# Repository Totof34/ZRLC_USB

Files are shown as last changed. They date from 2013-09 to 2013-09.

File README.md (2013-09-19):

ZRLC_USB
================

A small project to measure resistance, impedance, capacitance, inductance, input impedance of
amplifier, transformers, etc 

If you would have more information about this project please visit 
www.audiyofan.org

A link to the dedicated post 

http://www.audiyofan.org/forum/viewtopic.php?f=57&t=8121&start=30

It's just a box connected via USB , you don't need an external sound card to measure ZRLC,

You can use VisualAnalyser or an other program, A link to the dedicated to the software

http://www.sillanumsoft.org/ZRLC.htm

Under Linux no drivers is required
Under Windows you can find in the folder "Drivers_windows" all you need to run this box properly

PCB & schema are designed with Kicad

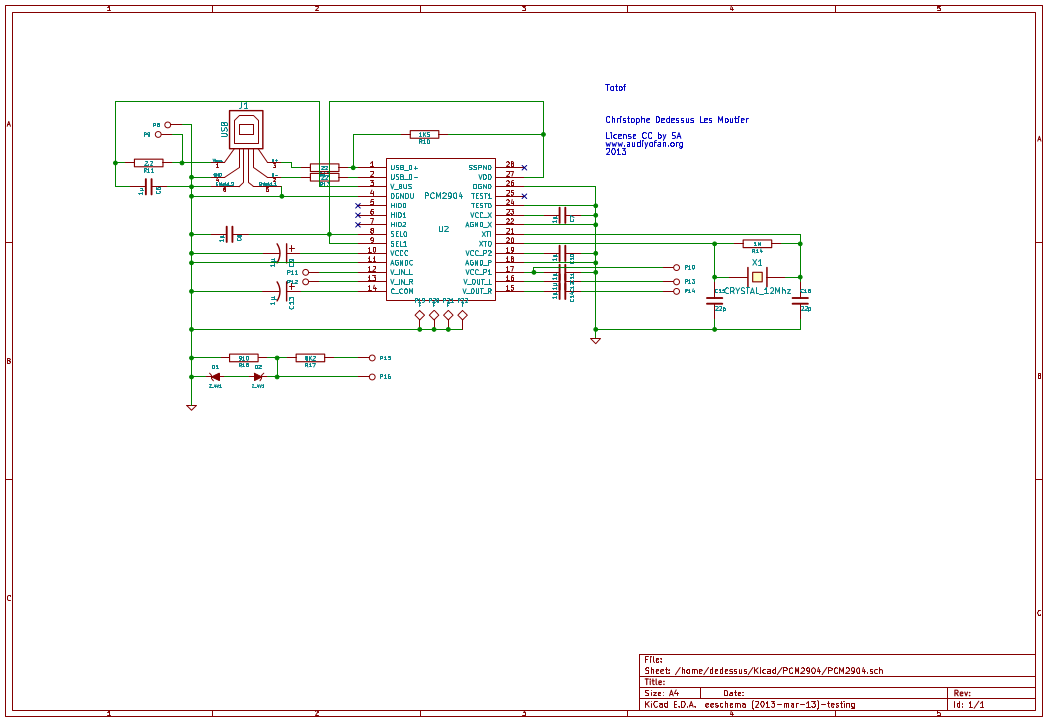
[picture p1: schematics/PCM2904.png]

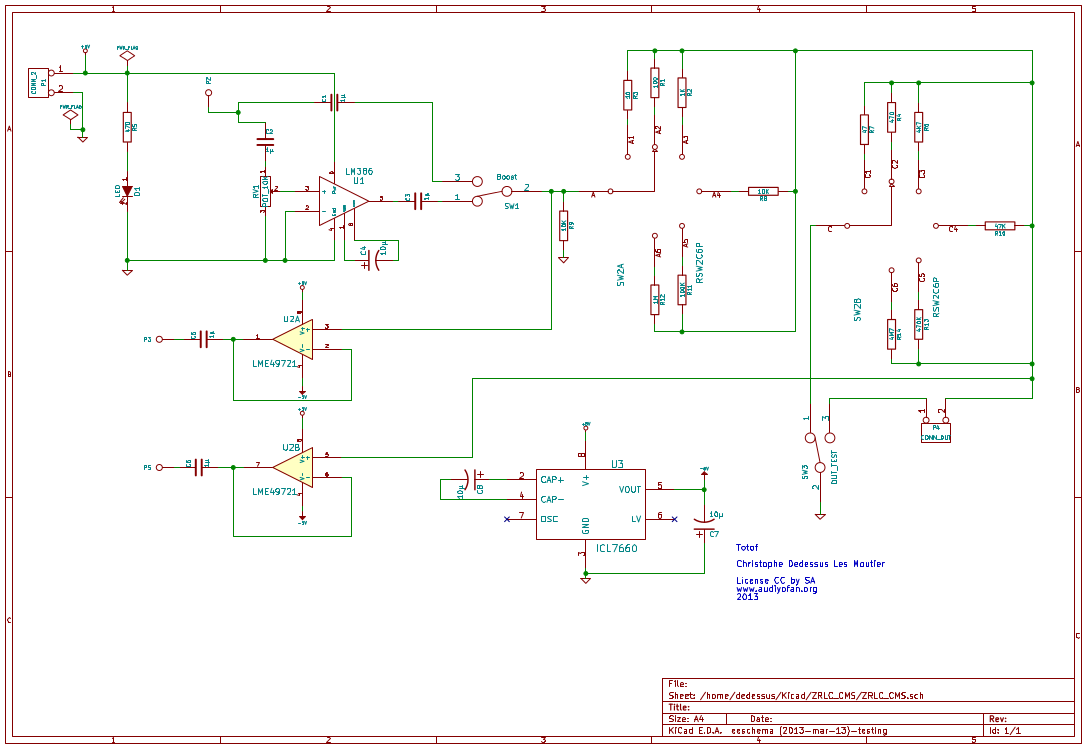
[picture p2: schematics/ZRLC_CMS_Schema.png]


All comments are welcome

Totof

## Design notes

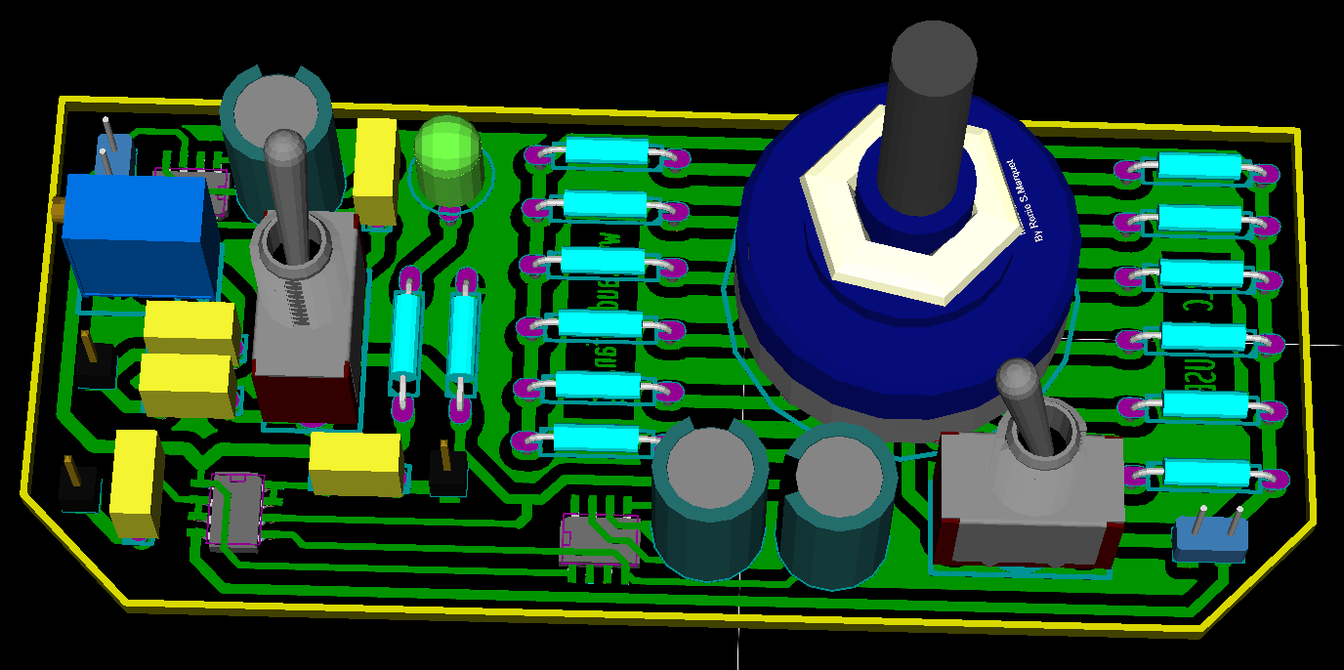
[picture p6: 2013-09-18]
images/ZRLC_CMS_3D.png

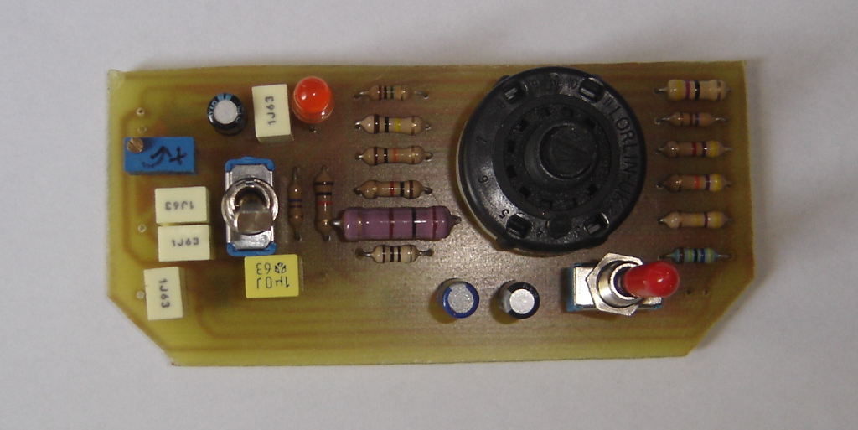
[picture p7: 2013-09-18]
images/PCB_ZRLC_CMS5.JPG

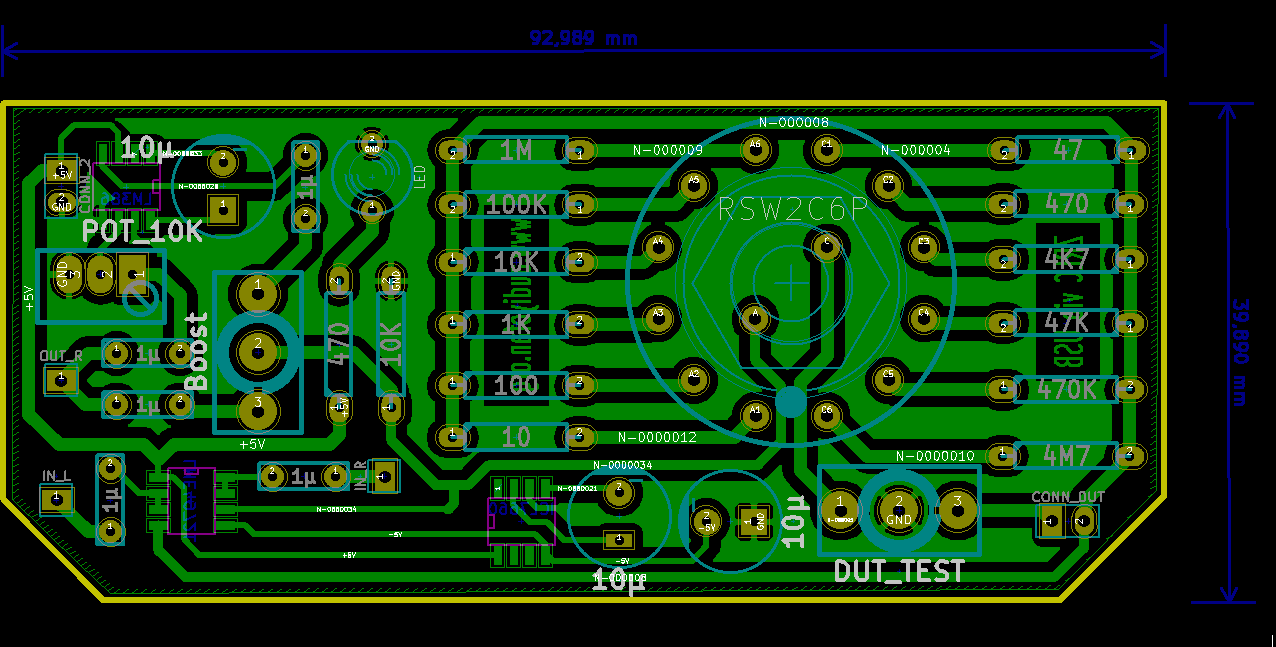
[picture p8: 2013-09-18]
images/ZRLC_CMS_PCB.png

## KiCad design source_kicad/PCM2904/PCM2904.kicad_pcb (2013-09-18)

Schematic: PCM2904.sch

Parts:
C6, C7, C8, C9, C10, C11, C12, C13, C14: 1µ
C15, C16: 22p
D1, D2: Z_4V1
J1: USB
P8: CONN_GND
P9: CONN_V+
P10: V_OUT
P11: V_IN_L
P12: V_IN_R
P13: V_OUT_L
P14: V_OUT_R
P15: CH2_IN
P16: CH2_OUT
P19, P20, P21, P22: F
R10: 1K5
R11: 2.2
R12, R13: 22
R14: 1M
R16: 910
R17: 8K2
U2: PCM2904
X1: CRYSTAL_12Mhz

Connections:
GND: C6.1, C7.1, C8.2, C9.2, C10.1, C11.1, C13.2, C15.2, C16.2, D1.2, J1.4 (GND), J1.5 (Shield_1), J1.6 (Shield_2), P8.1, P19.1, P20.1, P21.1, P22.1, R16.2, U2.4 (DGNDU), U2.11 (AGNDC), U2.18 (AGND_P), U2.22 (AGND_X), U2.24 (TEST0), U2.26 (DGND)
unnamed: C15.1, R14.2, U2.20 (XTO), X1.1
unnamed: C16.1, R14.1, U2.21 (XTI), X1.2
unnamed: C11.2, P10.1, U2.17 (VCC_P1)
unnamed: P11.1, U2.12 (V_IN_L)
unnamed: P12.1, U2.13 (V_IN_R)
unnamed: C12.1, P13.1
unnamed: C12.2, U2.16 (V_OUT_L)
unnamed: C14.1, P14.1
unnamed: C14.2, U2.15 (V_OUT_R)
unnamed: C10.2, U2.19 (VCC_P2)
unnamed: C7.2, U2.23 (VCC_X)
unnamed: P15.1, R17.1
unnamed: D2.2, P16.1, R16.1, R17.2
unnamed: D1.1, D2.1
unnamed: J1.3 (D+), R12.2
unnamed: R13.1, U2.2 (USB_D-)
unnamed: C6.2, R11.2, U2.3 (V_BUS)
unnamed: C8.1, R10.1, U2.8 (SEL0), U2.9 (SEL1), U2.27 (VDD)
unnamed: J1.2 (D-), R13.2
unnamed: C13.1, U2.14 (C_COM)
unnamed: C9.1, U2.10 (VCCC)
unnamed: J1.1 (Vbus), P9.1, R11.1
unnamed: R10.2, R12.1, U2.1 (USB_D+)

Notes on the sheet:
Totof Christophe Dedessus Les Moutier License CC by SA www.audiyofan.org 2013

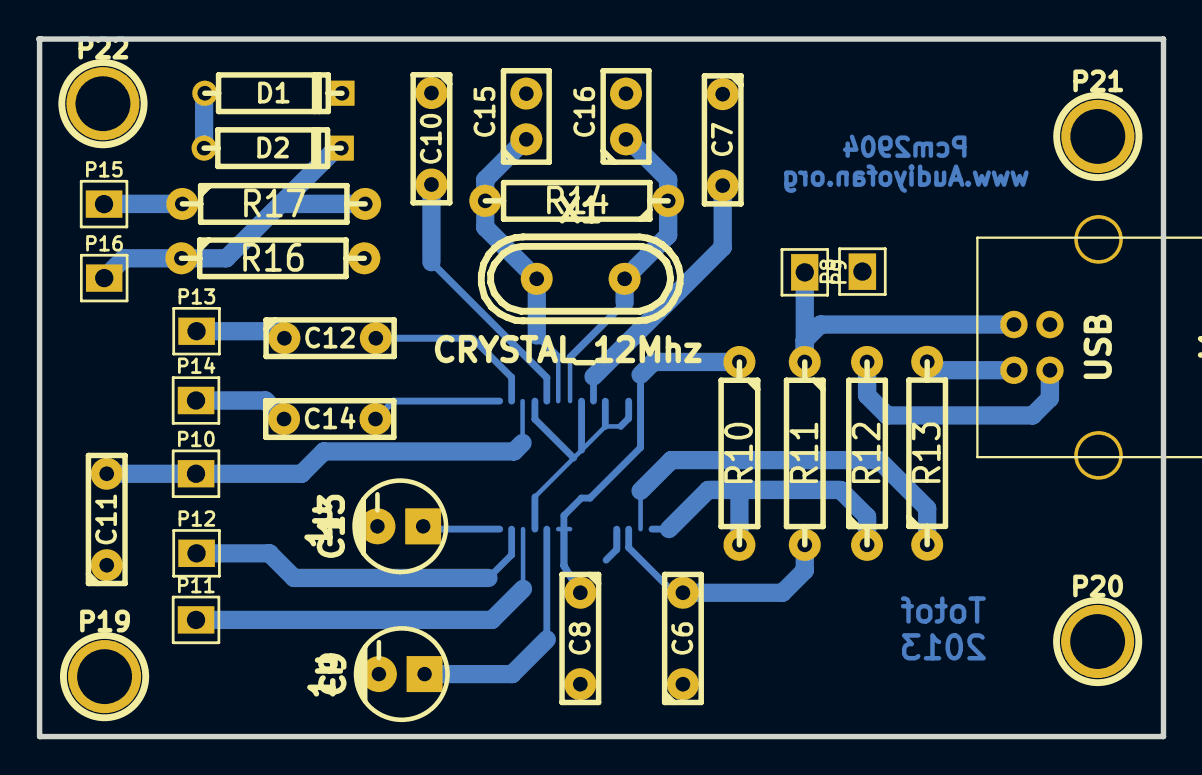
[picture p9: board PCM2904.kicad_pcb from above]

Board: 2 copper layers, 62.5 x 38.8 mm, 36 parts (1 on the bottom side), 24 nets.

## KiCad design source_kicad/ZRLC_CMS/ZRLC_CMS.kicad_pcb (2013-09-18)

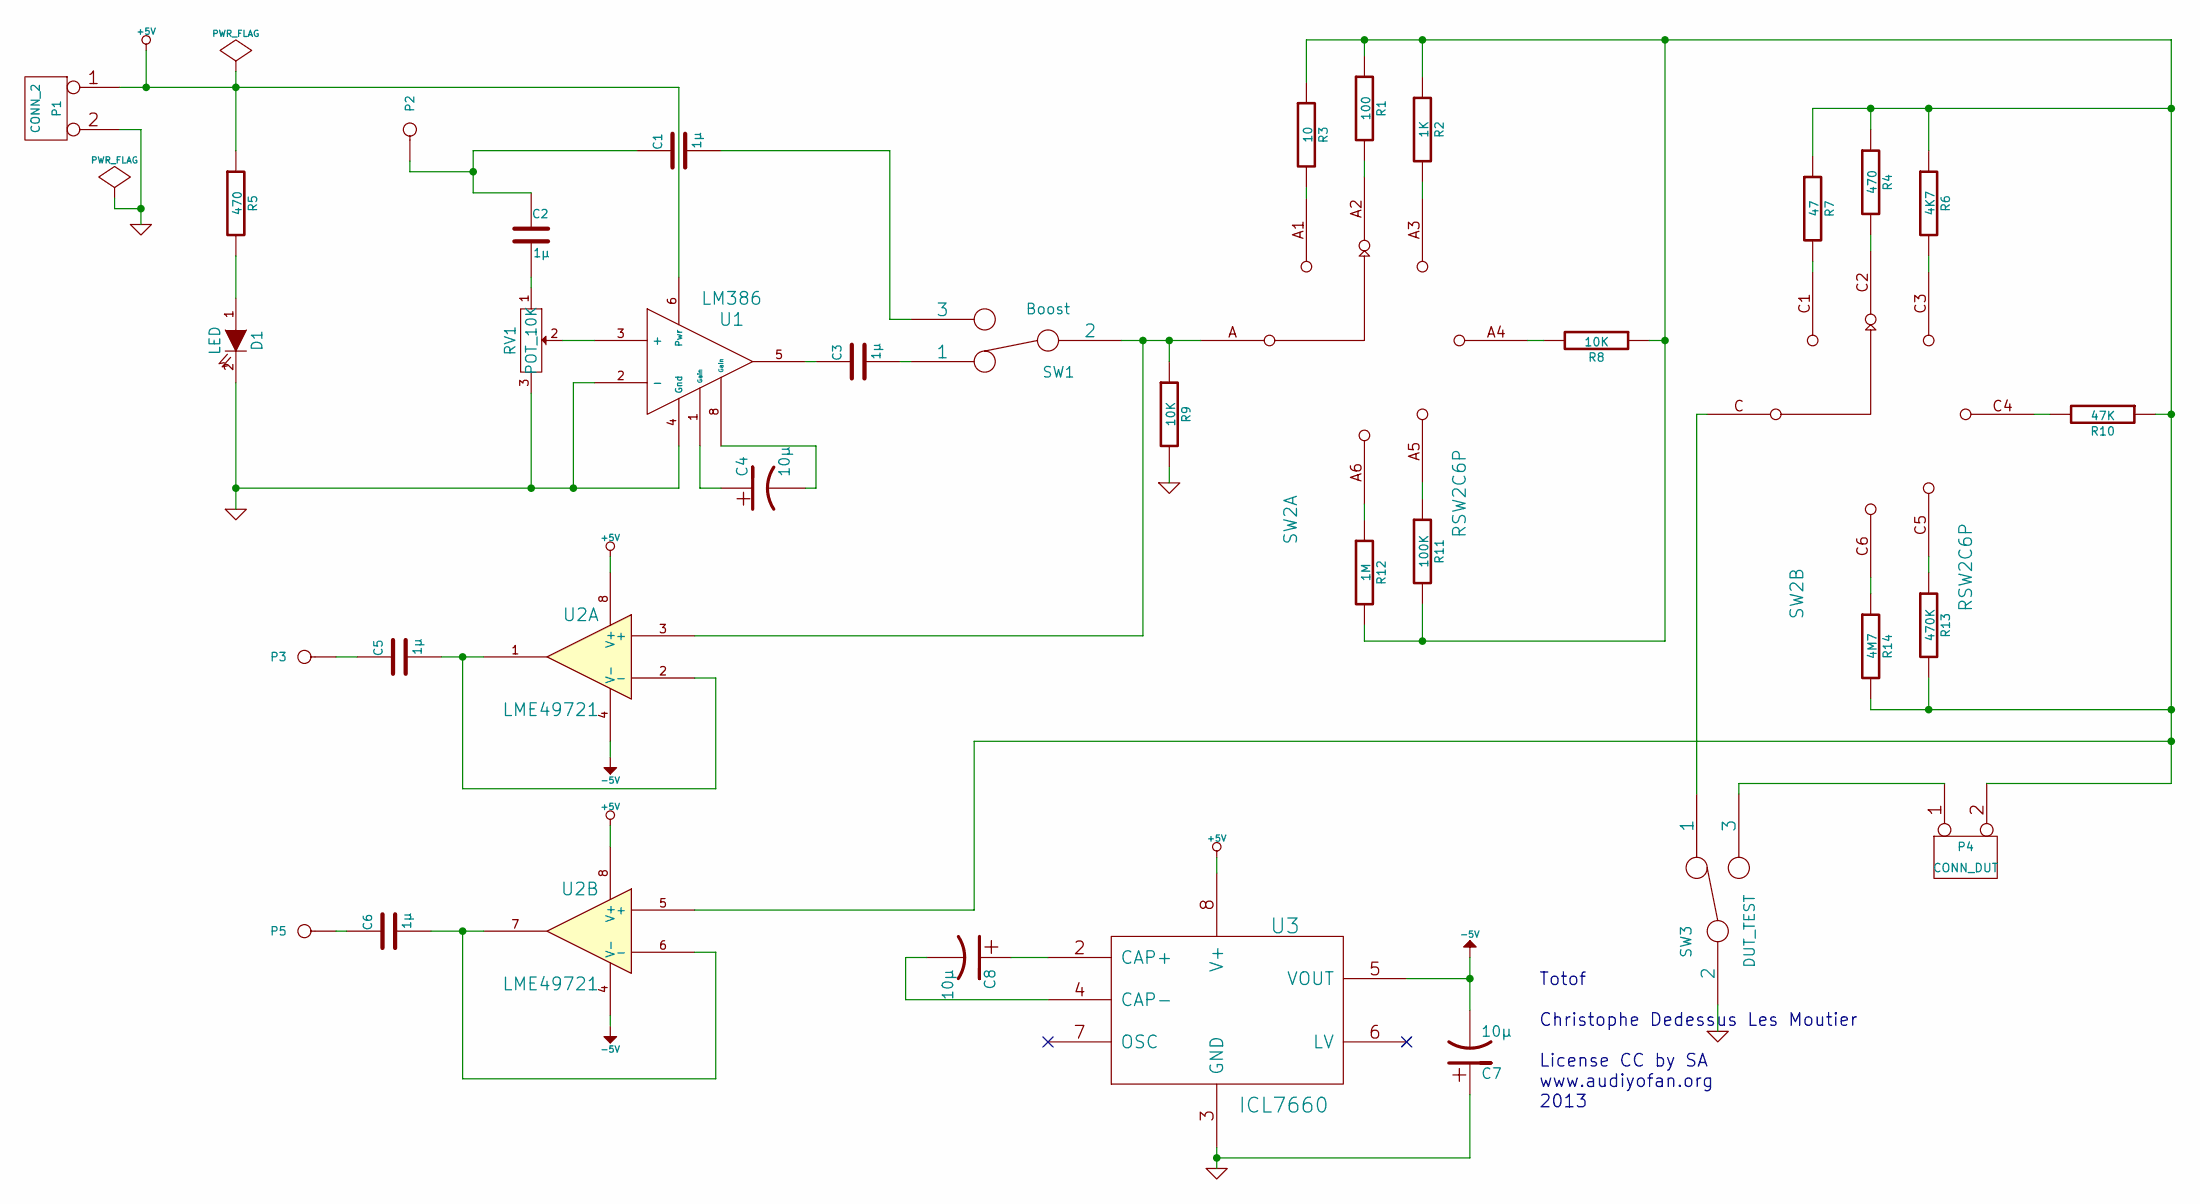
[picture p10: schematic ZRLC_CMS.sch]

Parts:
C1, C2, C3, C5, C6: 1µ
C4, C7, C8: 10µ
D1: LED
P1: CONN_2
P2: OUT_R
P3: IN_R
P4: CONN_DUT
P5: IN_L
R1: 100
R2: 1K
R3: 10
R4, R5: 470
R6: 4K7
R7: 47
R8, R9: 10K
R10: 47K
R11: 100K
R12: 1M
R13: 470K
R14: 4M7
RV1: POT_10K
SW1: Boost
SW2: RSW2C6P
SW3: DUT_TEST
U1: LM386
U2: LME49721
U3: ICL7660

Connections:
+5V: P1.1, R5.1, U1.6 (Pwr), U2.8 (V+), U3.8 (V+)
-5V: C7.2, U2.4 (V-), U3.5 (VOUT)
GND: C7.1, D1.2 (K), P1.2 (PM), R9.2, RV1.3, SW3.2, U1.2 (-), U1.4 (Gnd), U3.3 (GND)
unnamed: R10.2, SW2.C4
unnamed: R6.2, SW2.C3
unnamed: R4.2, SW2.C2
unnamed: R7.2, SW2.C1
unnamed: SW2.C, SW3.1
unnamed: P4.2 (PM), R1.1, R2.1, R3.1, R4.1, R6.1, R7.1, R8.1, R10.1, R11.2, R12.2, R13.2, R14.2, U2.5 (+)
unnamed: R12.1, SW2.A6
unnamed: R14.1, SW2.C6
unnamed: R13.1, SW2.C5
unnamed: R3.2, SW2.A1
unnamed: R1.2, SW2.A2
unnamed: R2.2, SW2.A3
unnamed: R8.2, SW2.A4
unnamed: R11.1, SW2.A5
unnamed: C8.1, U3.2 (CAP+)
unnamed: C8.2, U3.4 (CAP-)
unnamed: P4.1, SW3.3
unnamed: C6.1, P5.1
unnamed: D1.1 (A), R5.2
unnamed: C1.2, SW1.3
unnamed: C3.2, SW1.1
unnamed: RV1.2, U1.3 (+)
unnamed: C4.1, U1.1 (Gain)
unnamed: C3.1, U1.5
unnamed: C2.2, RV1.1
unnamed: C1.1, C2.1, P2.1
unnamed: C5.1, P3.1
unnamed: C4.2, U1.8 (Gain)
unnamed: R9.1, SW1.2, SW2.A, U2.3 (+)
unnamed: C5.2, U2.1, U2.2 (-)
unnamed: C6.2, U2.6 (-), U2.7

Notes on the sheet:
Totof Christophe Dedessus Les Moutier License CC by SA www.audiyofan.org 2013

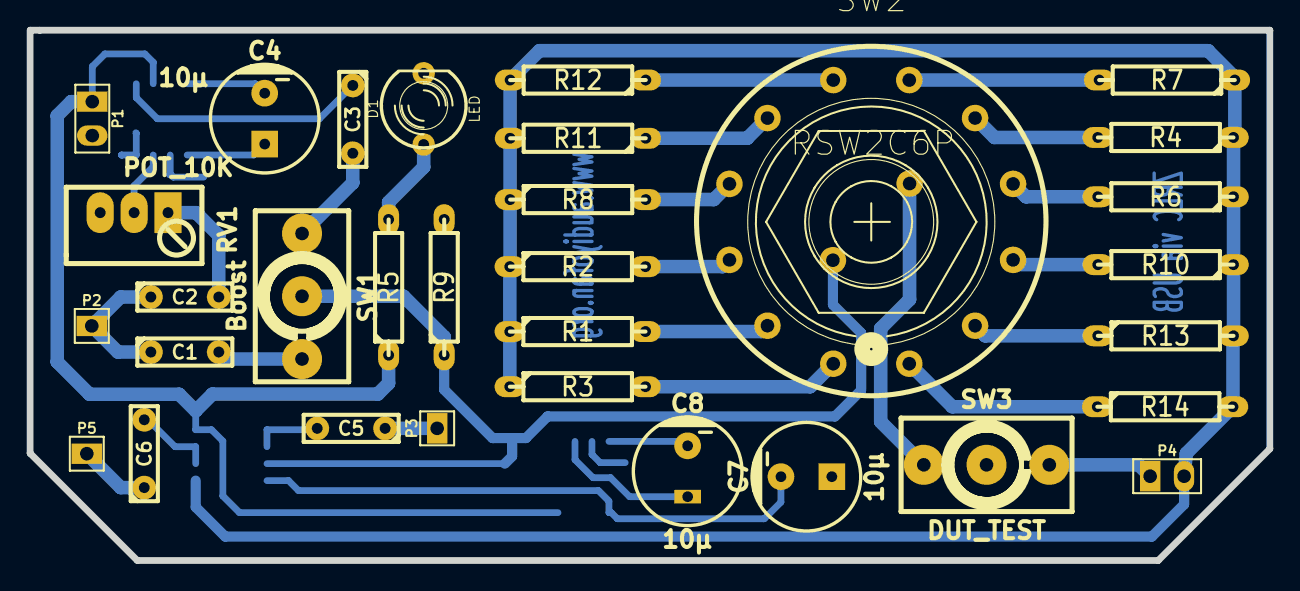
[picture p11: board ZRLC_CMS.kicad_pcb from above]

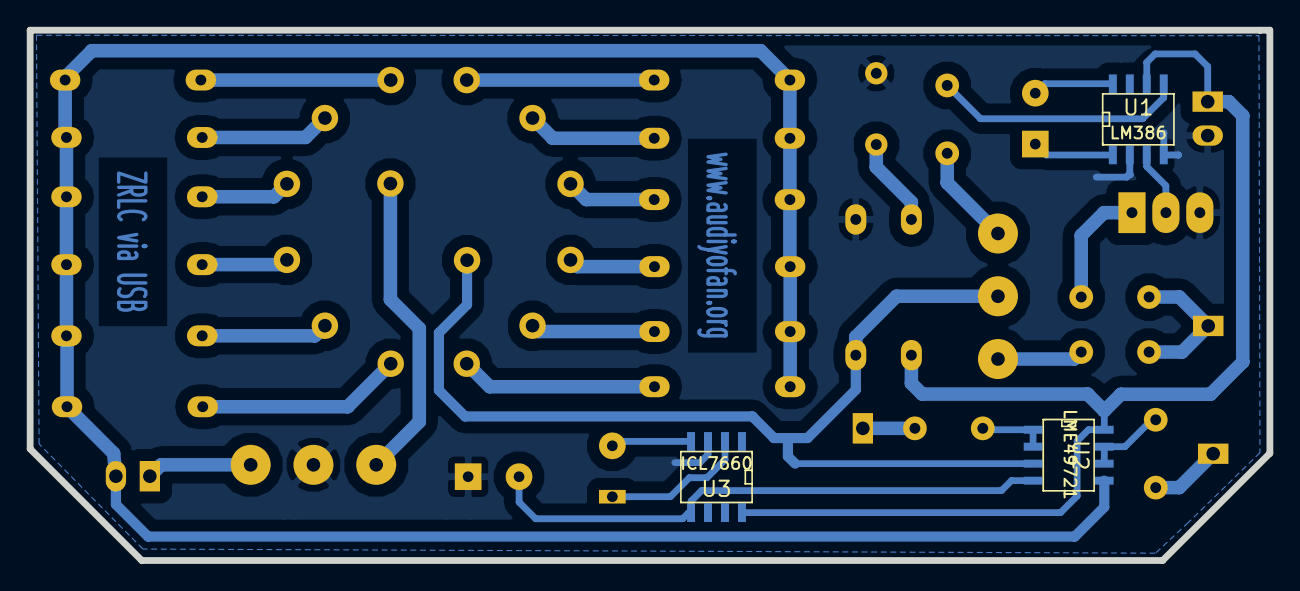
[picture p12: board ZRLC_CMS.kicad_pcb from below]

Board: 2 copper layers, 92.8 x 39.7 mm, 35 parts (3 on the bottom side), 34 nets.
